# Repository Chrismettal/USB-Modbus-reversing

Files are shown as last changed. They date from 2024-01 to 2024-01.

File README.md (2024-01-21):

# USB-Modbus reversing <!-- omit in toc -->





Documentation of a reversed no-name USB to Modbus converter. It seems to be using some non-standard automatic `DE/NRE` handling that I would like to use for my [PiPLC project](https://github.com/chrismettal/piplc) for software that can't use manual `DE/NRE` switching, like Home Assistant.

A KiCAD project is included, but only for reversing the original PCB, and not to recreate a new one. Though I might change my mind later.

**If you like my work please consider [supporting me](https://github.com/Chrismettal#donations)!**

## Table of contents <!-- omit in toc -->

- [Original](#original)
- [Reversing](#reversing)
- [Observations](#observations)
- [Donations](#donations)
- [License](#license)

## Original

These cheap thingies are listed as RS485/Modbus CH340 based converters. The "`CH340`" in question is unlabeled on the board and does not seem to be a `CH340` at all.
Interestingly, some parts are not populated. The parts in question seem to be the Crystal for a real CH340 as well as a termination resistor on the Modbus line.

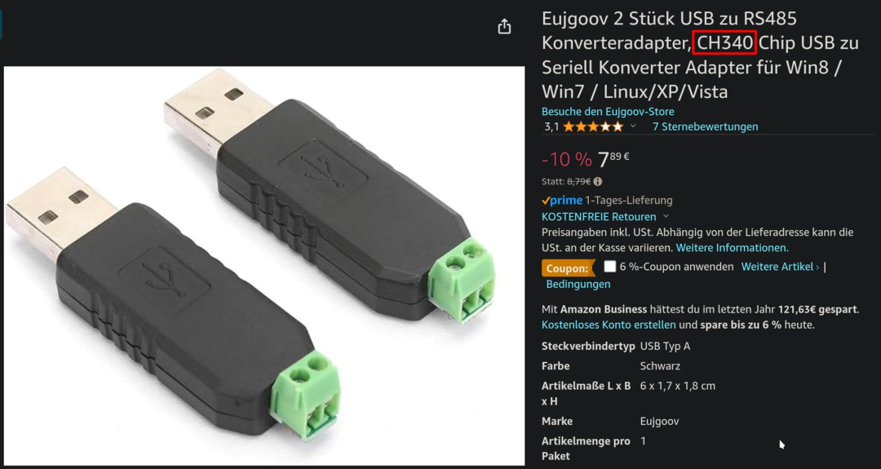
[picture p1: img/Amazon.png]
Amazon Listing


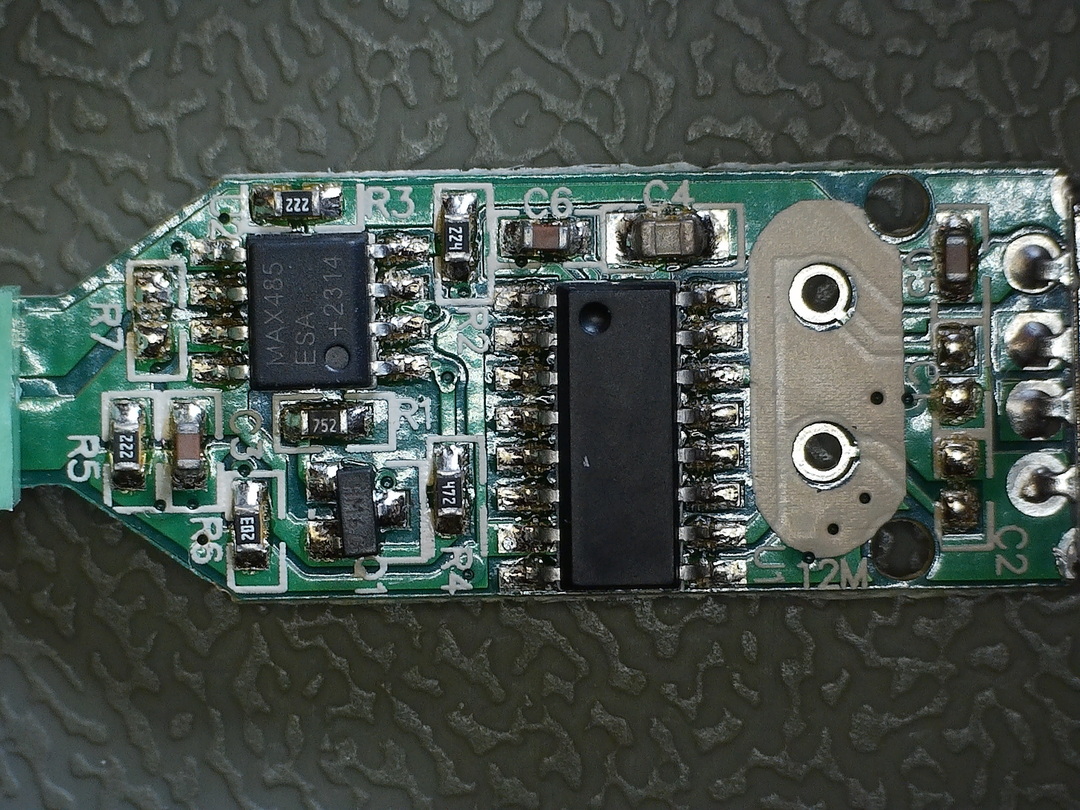
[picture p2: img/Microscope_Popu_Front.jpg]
MicroFront


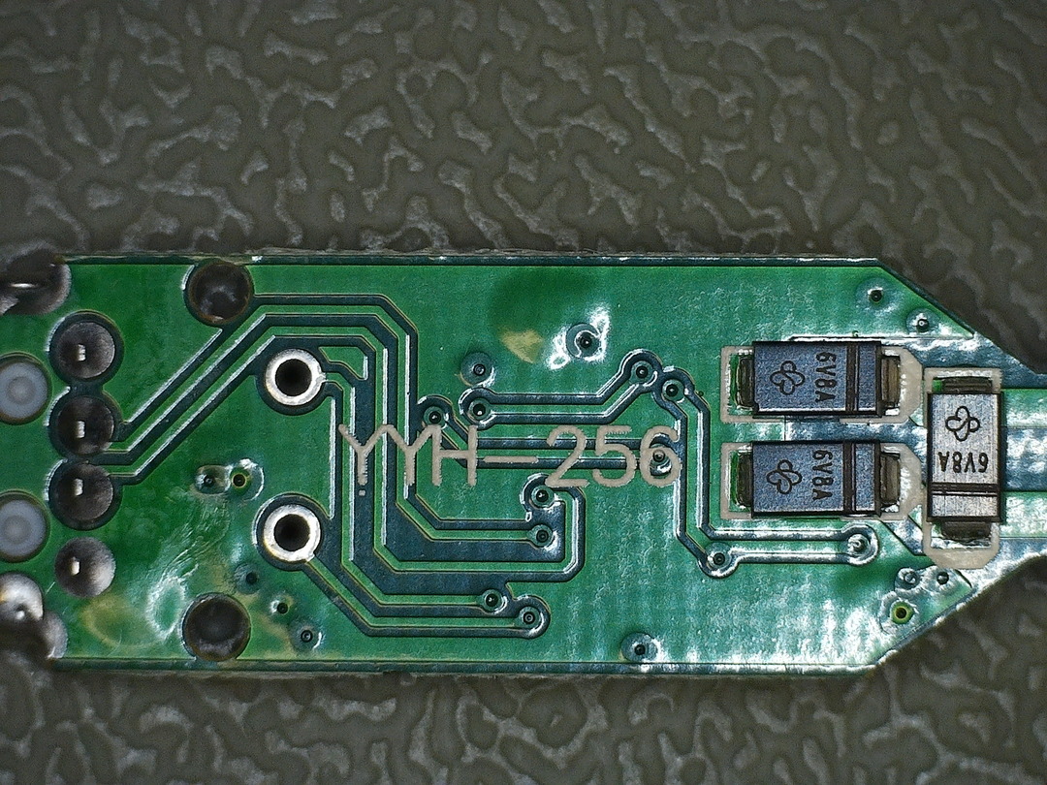
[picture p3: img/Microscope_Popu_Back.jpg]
MicroBack


## Reversing

The board was completely depopulated, while the unlabeled parts were being measured. After cleaning the bare boards up, they were scanned with a regular flat bed scanner.

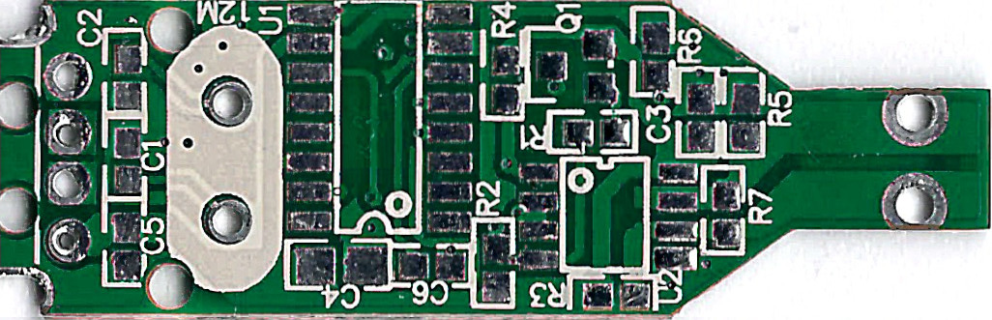
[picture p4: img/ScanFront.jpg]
ScanFront


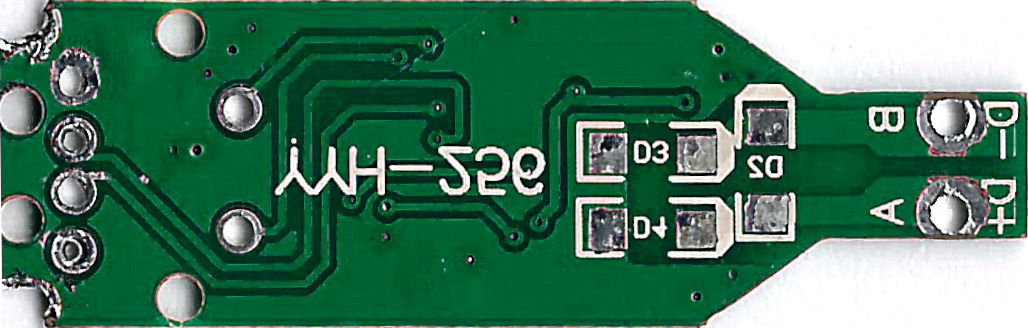
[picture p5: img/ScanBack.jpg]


These scans were imported into KiCAD as layer images to trace over. All depopulated parts were created in the Schematic view and placed on the image. Routing without first creating the schematic doesn't work, so we hop back and forth, routing over the image and in the schematic at the same time, until all traces from the image are traced over and all parts are connected.

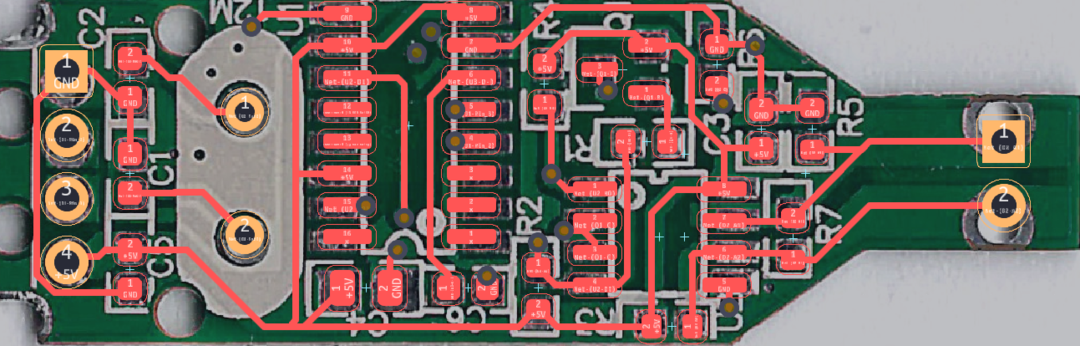
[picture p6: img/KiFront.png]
KiFront


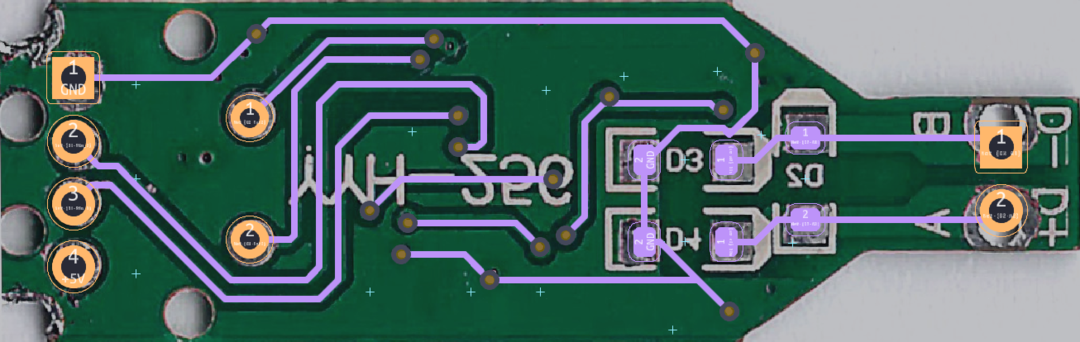
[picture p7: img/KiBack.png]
KiBack


This let's us end up with the following schematic:

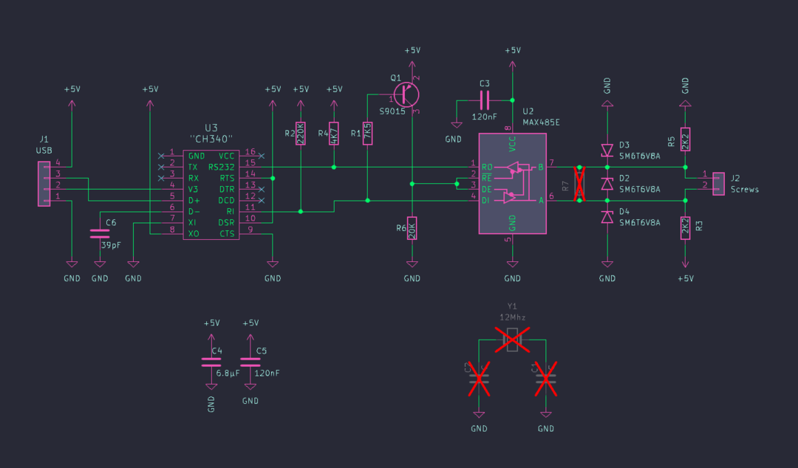
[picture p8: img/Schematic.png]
Schematic


## Observations

- The part that I wanted to see, the automatic `DE/NRE` switching, seems to be super cheap and highly optimistic, switching on the sending driver while `DI` is being pulled `LOW`. This should mean that `A` only sends `LOW` signals actively, while relying on pullups to set `A` back `HIGH`.
- While being so cheap that it doesn't even use active `DE/NRE` switching, the device still has input protection on the `A/B` Modbus lines.
- It also doesn't have the option for a terminating resistor. You could place `R7` manually, but a switch on the side would have been nice.
- The "`CH340`" as described on Amazon is almost certainly not a `CH340`.
- The unpopulated Crystal has lines going to Vias that just don't go anywhere. It looks like the board was originally designed for an actual `CH340` with a crystal, but was quietly modified to accept a different USB converter. Seeing that the crystal's traces just end on a via I assume that they just didn't bother cleaning the rest of the board up when the converter IC was changed.

## Donations

**If you like my work please consider [supporting me](https://github.com/Chrismettal#donations)!**

## License

 <br />This work is licensed under a <a rel="license" href="http://creativecommons.org/licenses/by-sa/4.0/">Creative Commons Attribution-ShareAlike 4.0 International License</a>.

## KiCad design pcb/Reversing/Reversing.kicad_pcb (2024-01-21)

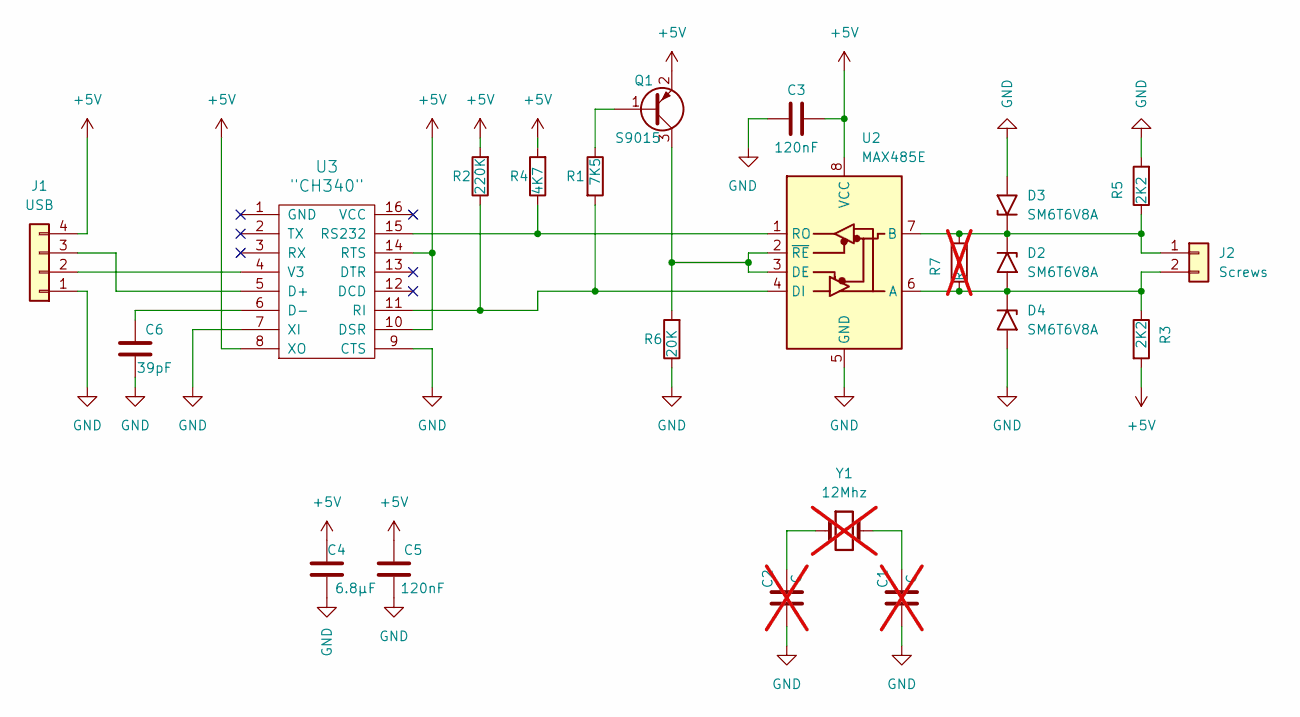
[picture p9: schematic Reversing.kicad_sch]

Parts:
C1, C2: C; C_0603_1608Metric; not fitted
C3, C5: 120nF; C_0603_1608Metric
C4: 6.8µF; C_0805_2012Metric
C6: 39pF; C_0603_1608Metric
D2, D3, D4: SM6T6V8A; D_SOD-123
J1: USB; PinHeader_1x04_P2.54mm_Vertical
J2: Screws; PinHeader_1x02_P2.54mm_Vertical
Q1: S9015; SOT-23; LCSC C2149
R1: 7K5; R_0603_1608Metric
R2: 220K; R_0603_1608Metric
R3, R5: 2K2; R_0603_1608Metric
R4: 4K7; R_0603_1608Metric
R6: 20K; R_0603_1608Metric
R7: R; R_0603_1608Metric; not fitted
U2: MAX485E; SO-8_3.9x4.9mm_P1.27mm
U3: "CH340"; SOIC-16_3.9x9.9mm_P1.27mm
Y1: 12Mhz; Crystal_HC18-U_Vertical; not fitted

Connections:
+5V: C3.1, C4.1, C5.2, J1.4, Q1.2 (E), R2.2, R3.2, R4.2, U2.8 (VCC), U3.8 (XO), U3.10 (DSR), U3.14 (RTS)
GND: C1.1, C2.1, C3.2, C4.2, C5.1, C6.2, D3.2 (A2), D4.2 (A2), J1.1, R5.2, R6.1, U2.5 (GND), U3.7 (XI), U3.9 (CTS)
unnamed: C1.2, Y1.2
unnamed: C2.2, Y1.1
unnamed: D2.1 (A1), D3.1 (A1), J2.1, R5.1, R7.2, U2.7 (B)
unnamed: D2.2 (A2), D4.1 (A1), J2.2, R3.1, R7.1, U2.6 (A)
unnamed: J1.2, U3.4 (V3)
unnamed: J1.3, U3.5 (D+)
unnamed: Q1.1 (B), R1.1
unnamed: Q1.3 (C), R6.2, U2.2 (~RE), U2.3 (DE)
unnamed: R1.2, R2.1, U2.4 (DI), U3.11 (RI)
unnamed: R4.1, U2.1 (RO), U3.15 (RS232)
unnamed: C6.1, U3.6 (D-)

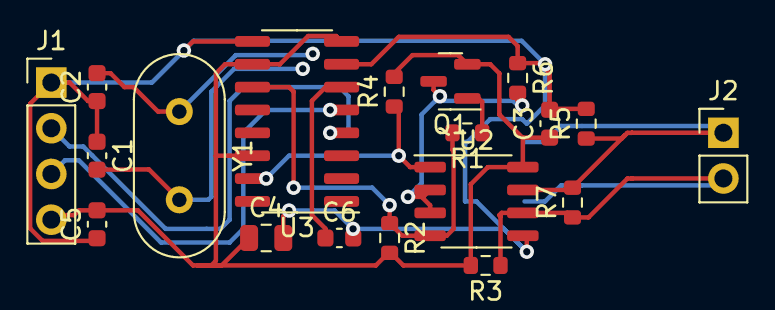
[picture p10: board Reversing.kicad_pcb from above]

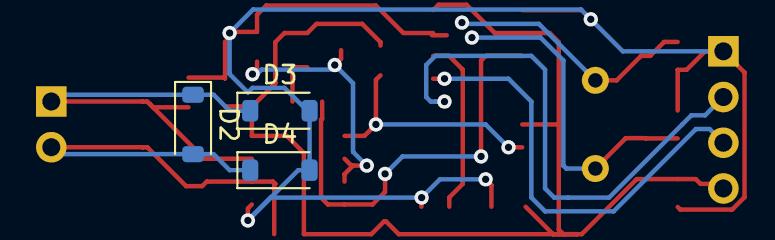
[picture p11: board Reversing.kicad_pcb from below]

Board: 2 copper layers, 22 parts (3 on the bottom side), 13 nets.

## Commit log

2024-01-21 Add initial project information
    [Reversing.kicad_pcb, Reversing.kicad_sch]
2024-01-21 Add assumed parts to KiCAD project
    [Reversing.kicad_sch]
2024-01-21 Reverse whole board in one swoop
    [Reversing.kicad_pcb, Reversing.kicad_sch]
2024-01-21 Fix Schematic embed

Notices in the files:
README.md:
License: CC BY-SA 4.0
